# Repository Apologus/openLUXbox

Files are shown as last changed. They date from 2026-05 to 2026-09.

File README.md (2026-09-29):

# openLUXbox
## DIY-Open-Source-Coop-**Spielekonsole**
### Bauanleitung, 3D-Dateien, Dokumentation

*openLUXbox ist eine offene DIY-Spielekonsole für unter 40€ – gebaut zum Spielen, gedacht zum Weitermachen.*

Die openLUXbox wurde durch das *WLED Project* und das *Open LED Race Project* inspiriert. Die Grundidee besteht darin, eine einfache DIY-Hardware als Basis für **kooperative Spiele** zu nutzen. Die Steuerung erfolgt über vier integrierte Push-Buttons.

Die Hardware besteht aus einer LED-Matrix (WS2812b, 16x16 LEDs), einem ESP8266, 4 Buttons und wenigen Kleinteilen. Das Gehäuse ist 3D-gedruckt. Die Gesamtkosten bei ca. 30€.

Sämtliche Dokumente (Bauanleitung, Dokumentation, 3D-Druckdateien, Anleitung zum Programmieren) stehen frei zur Verfügung.

Die Zahl der Spiele wächst stetig. Diese können über einen Webflasher direkt aufgespielt werden. Das Besondere ist, dass diese Spiele per *Vibe Coding* entstanden sind. Das heißt, die Beschreibung der gewünschten Spielefunktion wurde durch KI in Arduino-Code umgesetzt. Dadurch sind nur rudimentäre Programmierkenntnisse notwendig, um **eigene Spiele** zu erstellen.

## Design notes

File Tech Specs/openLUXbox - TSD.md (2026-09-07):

### Technichal Specification Document

Dieses Dokument beschreibt die Funktionen und Spezifikationen einer Spielekonsole, die einen ESP8266  als Prozessor und eine 16x16 LED-Matrix als Ausgabe hat. 4 Buttons dienen der Bedienung und Steuerung.

## 1\. Hardware

### 1.1 Microcontroller:

D1 Mini NodeMcu mit ESP8266-12F
Treiber: "NodeMCU 1.0 (ESP-12E Module)" soll als Hinweis in jedem Code ganz oben stehen.

### 1.2 Display

RGB LED Panel WS2812B 16x16 256 LEDs

Helligkeit: 20%
Angesteuert über GPIO D4 mit FastLED.
Wlan/Watchdogs deaktiviert.
Framerate abhängig vom jeweiligen Spiel. Ziel: 30 FPS.

LED-Matrix Verkabelung:
- Typ: WS2812B, 16x16, 256 LEDs, Serpentinen-Layout
- Startpunkt: oben rechts
- Zeile 0 (oben): läuft von rechts nach links (Index 0 = oben rechts)
- Zeile 1: läuft von links nach rechts
- Gerade Zeilen (0, 2, 4, ...): rechts → links
- Ungerade Zeilen (1, 3, 5, ...): links → rechts

Koordinaten-Mapping (olb_xy):
  if (y % 2 == 0) → Index = y * 16 + (15 - x)   // rechts→links
  if (y % 2 == 1) → Index = y * 16 + x           // links→rechts

Bilddaten in den FRAME-Arrays sind logisch gespeichert:
  Index 0 = oben links, zeilenweise von links nach rechts.
  Die olb_xy()-Funktion übernimmt die Umsetzung auf die physikalische Verkabelung.

### 1.3 Buttons

4 Pushbuttons an GPIO

| | | | |
| --- | --- | --- | --- |
| D-PIN | GPIO | Richtung | Buttonfarbe |
| D5  | 14  | links | gelb |
| D2  | 4 | rechts | grün |
| D1  | 5 | unten | weiß |
| D6  | 12  | hoch | blau |

#### 1.3.1 Button Electrical Specification

Die Pushbuttons sind jeweils wie folgt verschaltet:

- Ein Kontakt des Buttons liegt am GPIO-Pin
- Der andere Kontakt liegt an GND
- Es sind keine externen Widerstände verbaut

###### 1.3.1.1 Elektrisches Verhalten

- Interne Pullup-Widerstände des ESP8266 werden verwendet
- Pin-Konfiguration im Code:
    - pinMode(PIN, INPUT_PULLUP)

##### 1.3.2 Logik

- Ruhestand (nicht gedrückt): HIGH
- Gedrückt: LOW
- Interpretation im Code:
    - digitalRead(pin) == LOW → Button gedrückt
    - digitalRead(pin) == HIGH → Button nicht gedrückt

##### 1.3.3 Taster-Auswertung

- Ein Tastendruck wird nur beim Flankenwechsel erkannt:
    - HIGH → LOW
- Gedrückt-Halten darf keine Mehrfachbewegung auslösen
- Entprellung per Software mit 30ms Sperrzeit nach Flankenwechsel

### 1.4 Weiteres

Tonausgabe ist nicht implementiert.
Eine Debug-Ausgabe erfolgt über den Seriellen Monitor.

## 2\. Coding Guidelines

- Der Code muss vollständig Arduino-IDE kompatibel sein
- Alle Funktionen müssen entweder:
    - vor ihrem ersten Aufruf definiert sein
    - oder per Prototyp deklariert werden
- Funktions-Prototypen müssen nach den Includes stehen
- Keine Abhängigkeit von automatischer Arduino-Prototypgenerierung
- Alle Spielparameter müssen als Konstanten im oberen Codebereich definiert sein
- Gameplay-Logik darf nicht blockierend sein (millis-basiert)
- Der Code muss strukturiert sein:
    - Includes
    - Defines
    - Structs
    - Prototypen
    - Globale Variablen
    - setup()
    - loop()
    - Funktionsimplementierungen
- Zufallsfunktionen sollen nicht bei jedem Spielstart die gleichen Werte liefern. Die Werte sollen wirklich zufällig sein: Seed wird aus `analogRead` eines unbeschalteten Pins ermittelt.
- Startbildschirm vor Start eines Spiels.
- Bei Game over ein entsprechender Bildschirm. Neustart nach Tastendruck.
- Weitere Design-Regeln werden im jeweiligen Game Specification Document erläutert.

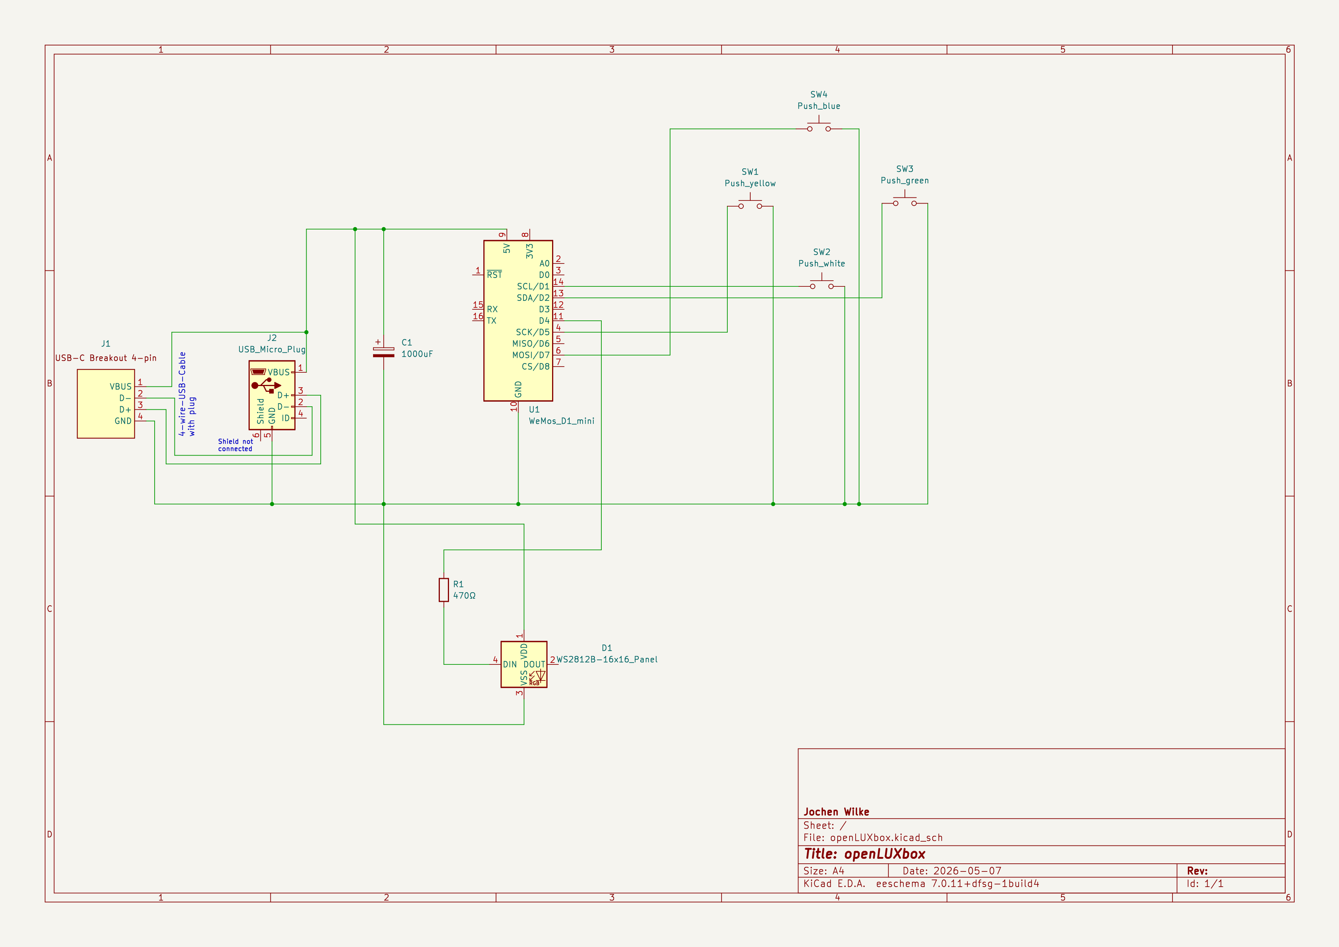
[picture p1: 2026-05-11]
Tech Specs/openLUXbox_kicad.png

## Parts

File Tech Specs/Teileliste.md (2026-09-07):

## Teileliste

Die Links sind *keine* affiliate links. Nachdem AZ-Delivery leider Konkurs angemeldet hat, stammen alle Links von Amazon.

- **ESP8266 Mini NodeMcu**: bei [Amazon](https://www.amazon.de//dp/B0C3LTYZDN).
- **LED Panel 16x16**: bei [Amazon](https://www.amazon.de/dp/B0DQSLL8P5).
- **USB-C-Buchsen** bei [Amazon](https://www.amazon.de/dp/B0CWNW6686).
- **USB-C-Anschlusskabel** bei  [Amazon](https://www.amazon.de/dp/B0CWNW6686).
- **Push Buttons**: bei [Amazon](https://www.amazon.de/dp/B0C5X3N5SR).
- **Widerstand 470 Ohm**: bei [Amazon](https://www.amazon.de/dp/B07BPK8V62).
- **Kondensatoren 1000uF**: bei [Amazon](https://www.amazon.de/dp/B0CMQBD1C3).

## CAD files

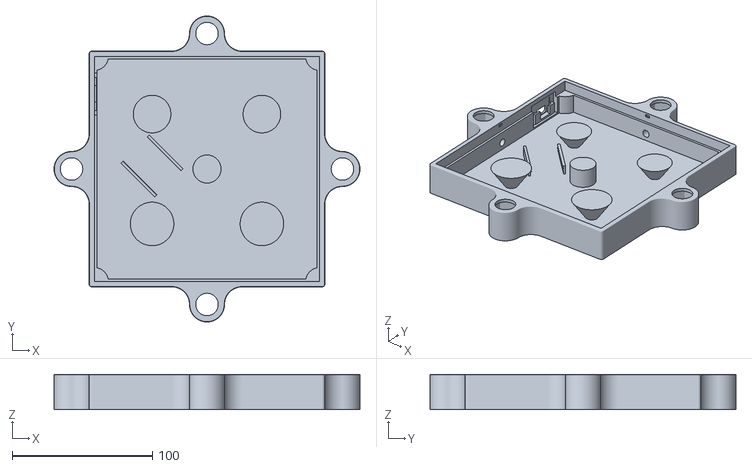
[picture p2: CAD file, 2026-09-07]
3d files/OpenLuxBox_Case_v2a.stl
218.0 x 218.0 x 25.0

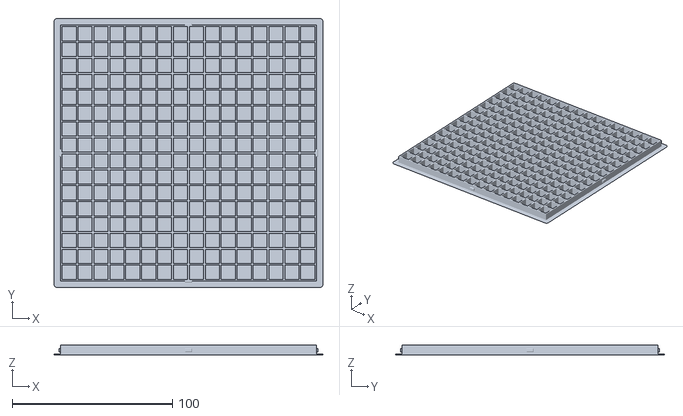
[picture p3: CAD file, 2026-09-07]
3d files/OpenLuxBox_Cover_v2a.stl
168.0 x 168.0 x 6.47

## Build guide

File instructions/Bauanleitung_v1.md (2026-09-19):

# openLUXbox
## Bauanleitung V1
Diese Anleitung beschreibt den Bau der openLUXbox v1. Alle benötigten Teile können selbst bestellt werden (siehe Teileliste). Case + Cover müssen 3d-gedruckt werden. Dieser vereinfache Aufbau ist inspiriert von 1ST1 aus dem [Homecon-Forum](https://forum.homecon.org/). 
### Case + Cover
Beide Teile sind mit PLA gedruckt. 
Das Case wird in einem Stück gedruckt. Dabei sind Stützen zu aktivieren. 
Das Cover besteht ebenfalls aus PLA. Die ersten Schichten sind einfach weißes PLA, das trennende Raster schwarzes PLA. Ohne Multifarbdrucker ist beim Slicen mit dem Beginn des Rasters ein Farbwechsel einzustellen.

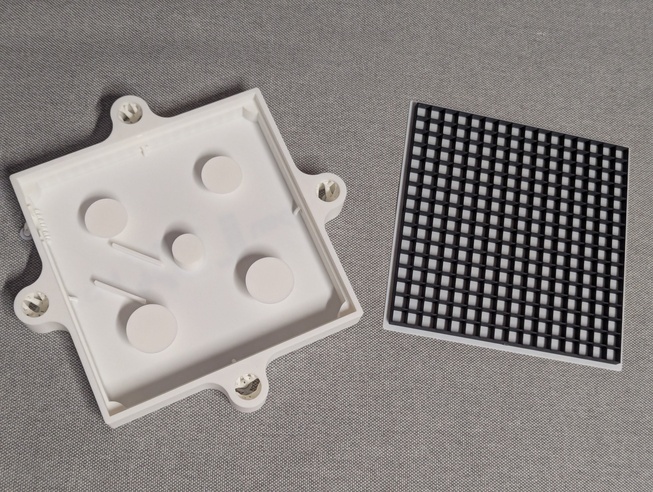
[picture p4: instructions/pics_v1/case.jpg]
Gehäuse


### Verkabelung
Der ESP8266 wird später in diese Halterung geschoben.

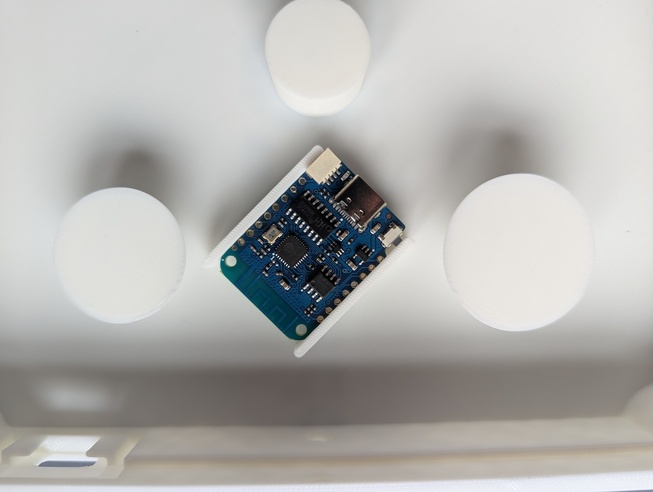
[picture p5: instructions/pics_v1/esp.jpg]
ESP


Die Stromversorgung erfolgt über eine USB-C-Buchse, an die ein Stecker angelötet wird. Dieser versorgt den ESP mit +5V/GND und zwei Datenleitungen, um Spiele zu flashen.

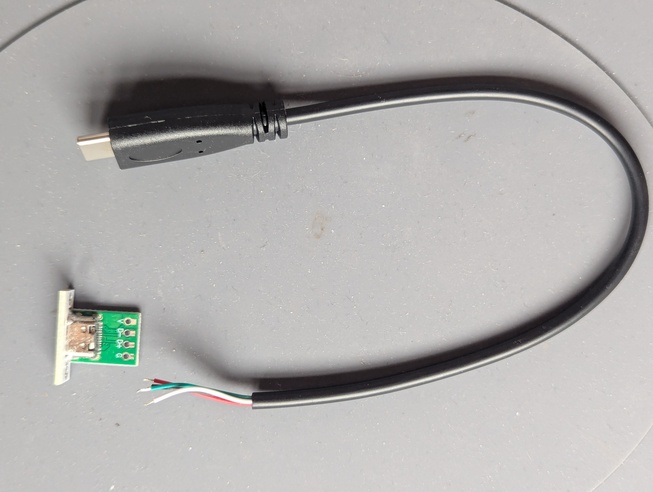
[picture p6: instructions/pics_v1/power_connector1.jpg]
Power Connector

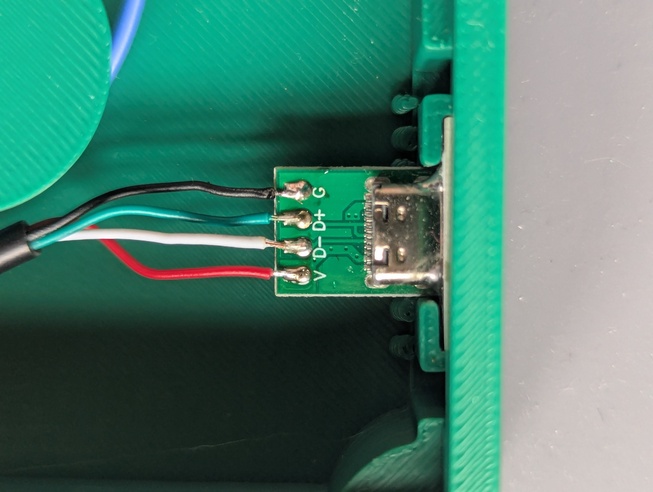
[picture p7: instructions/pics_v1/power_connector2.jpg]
Power Connector


Die Buttons haben einen Distanzring und eine Gewindemutter. Zwei Kabel (ca. 20cm) werden angelötet (oder sind es bereits).

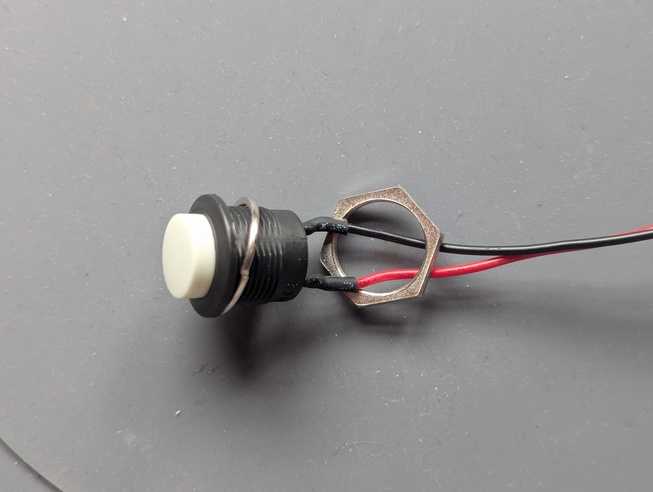
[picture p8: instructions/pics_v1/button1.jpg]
Button


Die Mutter wird von unten in den Halterungen der Buttons gesetzt.

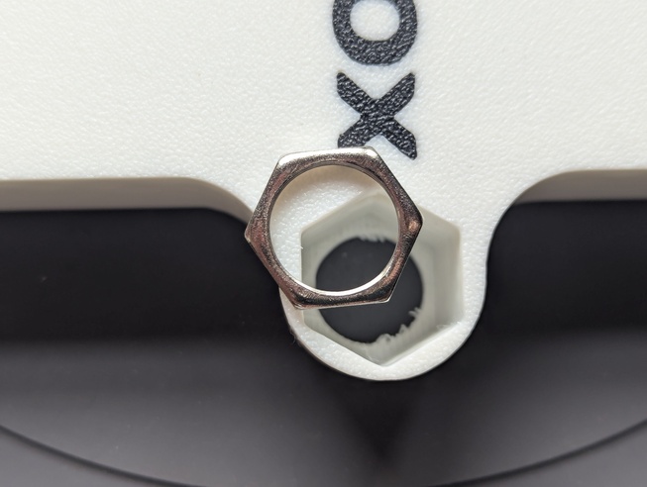
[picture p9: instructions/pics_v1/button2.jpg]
Button


Der Buttton wird dann von oben mit Distanzring und Kabeln eingeführt und in die Mutter eingedreht. Sitzt der Button fest, werden die beiden Kabel durch die Öffnung nach innen geführt.

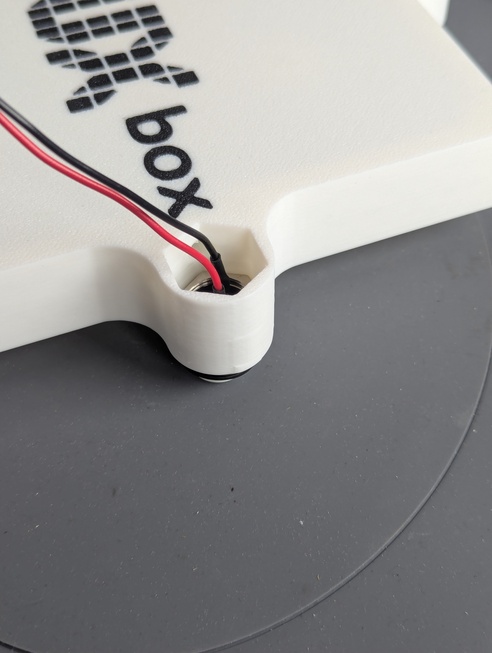
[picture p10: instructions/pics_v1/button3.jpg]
Button

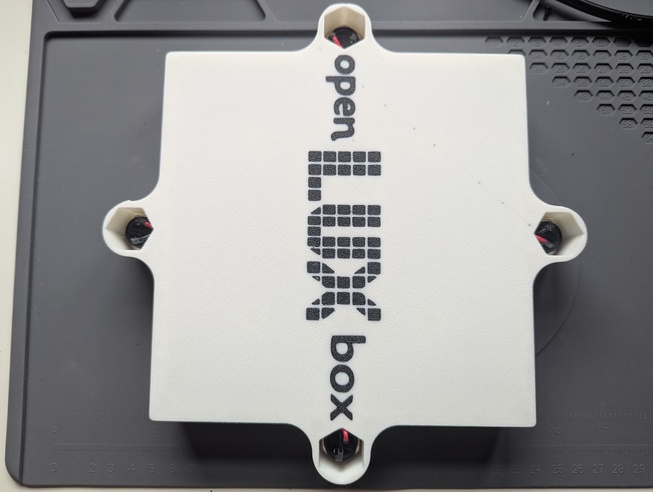
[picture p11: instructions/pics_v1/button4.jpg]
Button

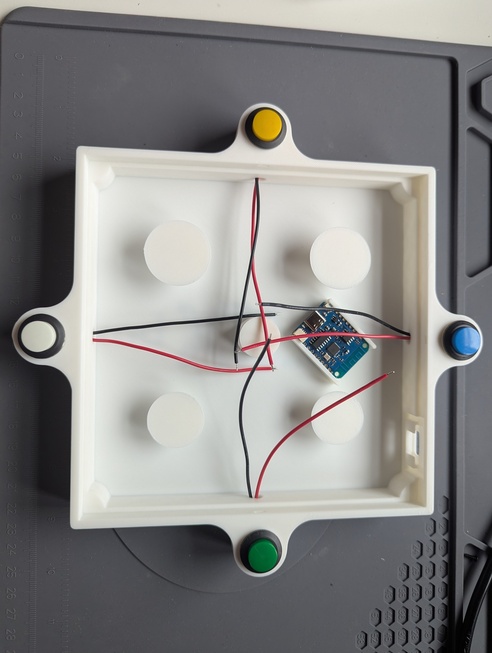
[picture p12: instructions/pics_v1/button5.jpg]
Button


Die roten Kabel der Buttons entweder direkt an den ESP gelötet werden. Alternativ (wie im Bild) lötet man kurze Verbindungskabel in der jeweiligen Buttonfarbe an den ESP. Diese werden dann mit den roten Kabeln des jeweiligen Buttons verbunden.

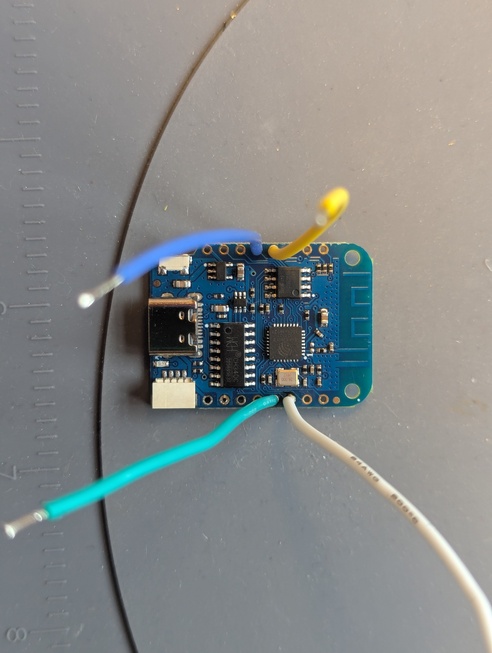
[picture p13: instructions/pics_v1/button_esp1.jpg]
Button_esp

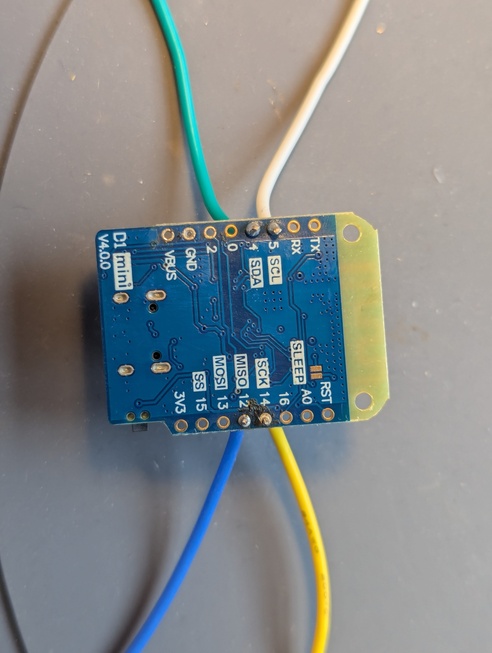
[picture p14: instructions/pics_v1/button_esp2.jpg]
Button_esp


Zwischen ESP und die Datenverbindung des LED (grünes Kabel) wird der Widerstand gelötet.

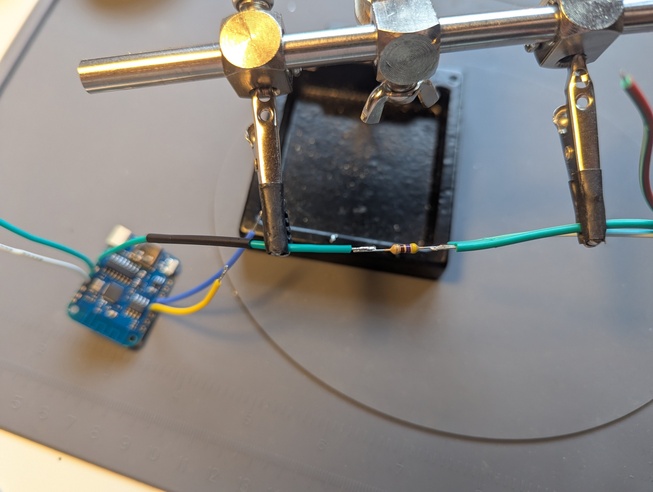
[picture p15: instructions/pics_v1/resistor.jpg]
resistor


Hier die vollständige Beschaltung des ESP.

PIN 4 ist dabei der grüne Button. PIN 2 die Datenverbindung zum LED.

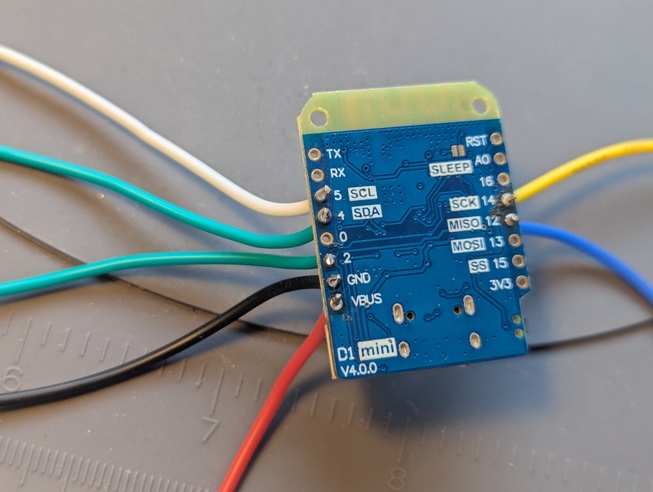
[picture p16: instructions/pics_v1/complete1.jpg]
complete1

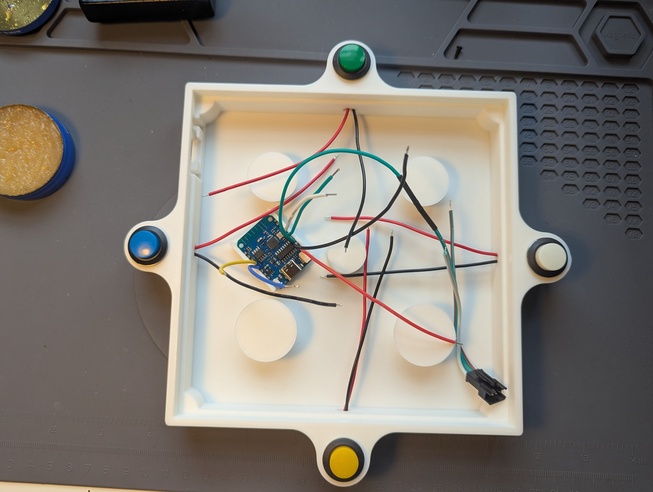
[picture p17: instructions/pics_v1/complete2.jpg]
complete2


Der Kondensator und die Spannungsversorgung des LED-Panels werden direkt an die USB-C-Buchse (von unten) gelötet.

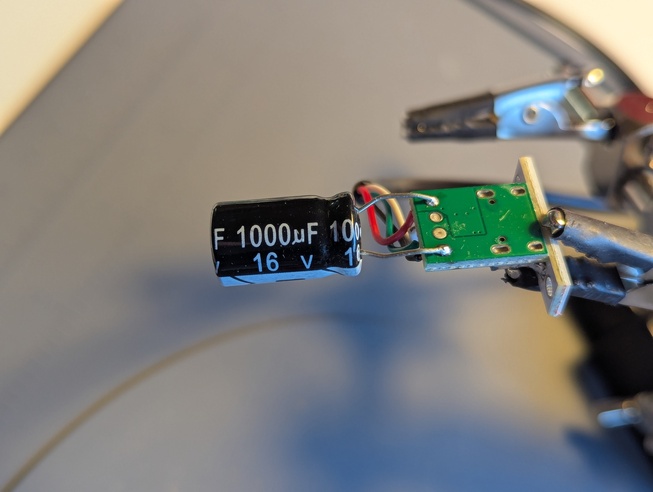
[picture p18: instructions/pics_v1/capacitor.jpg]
capacitor

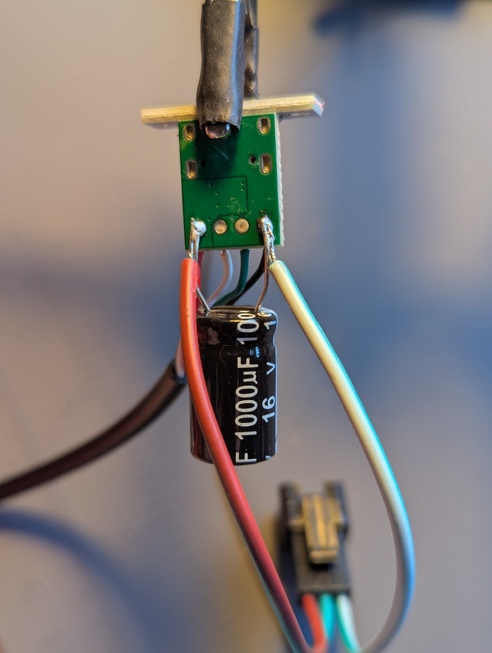
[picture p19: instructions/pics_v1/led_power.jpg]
led_power


Die vier schwarzen Kabel der Buttons (GRD) werden miteinander und einem weiteren Kabel verlötet. Das weitere Kabel kommt ebenfalls an GRD der USB-C-Buchse. Alle fünf Kabel am besten mit Schrumpfschlauch schützen.

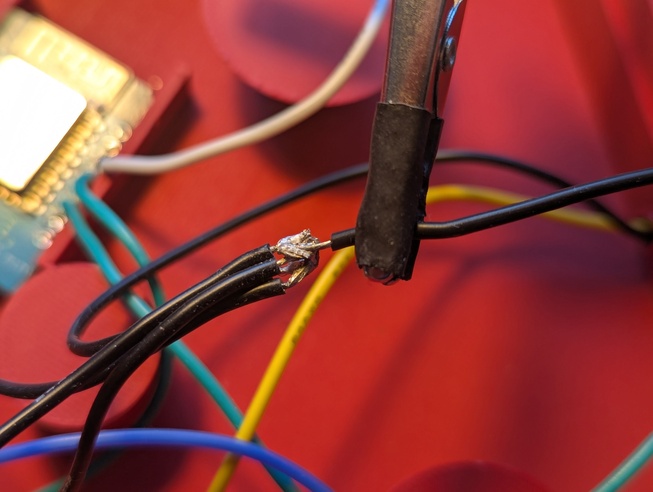
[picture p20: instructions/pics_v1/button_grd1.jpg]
button_grd1

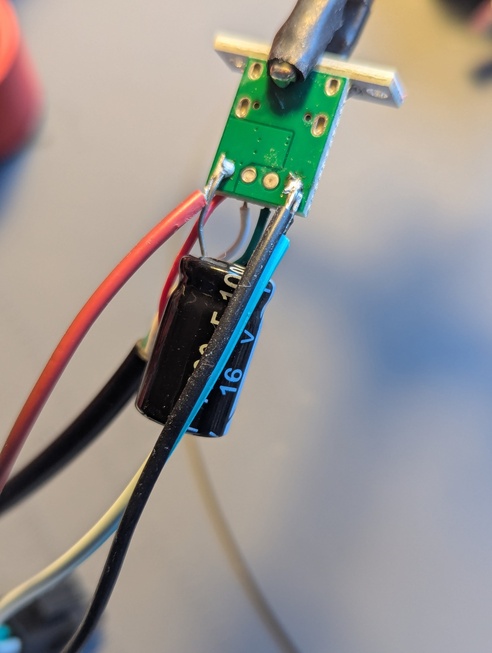
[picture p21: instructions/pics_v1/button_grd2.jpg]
button_grd2


Der komplette Aufbau sieht dann so aus.

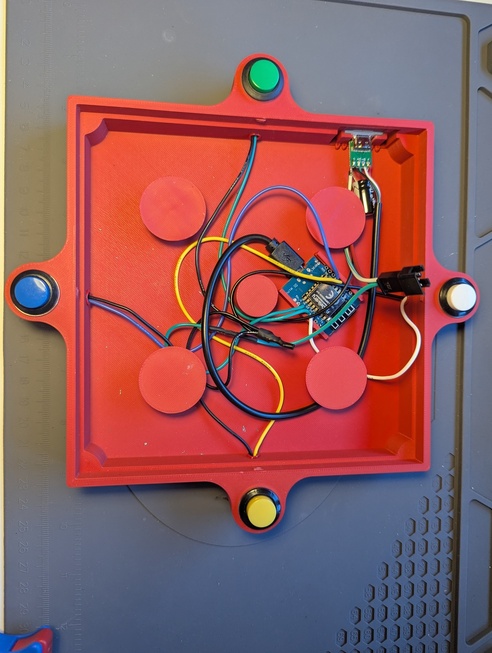
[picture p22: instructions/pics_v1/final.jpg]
final


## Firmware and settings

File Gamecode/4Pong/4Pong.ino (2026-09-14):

// NodeMCU 1.0 (ESP-12E Module)
// 4Pong - openLUXbox

#include <FastLED.h>
#include <ESP8266WiFi.h>
#include "olb_init_v1.h"

// ============================================================
// DEFINES / PARAMETER
// ============================================================
#define LED_PIN        D4
#define NUM_LEDS       256
#define MATRIX_W       16
#define MATRIX_H       16
#define BRIGHTNESS     51   // 20% von 255

#define BTN_LEFT       4    // D2 grün
#define BTN_RIGHT      14   // D5 gelb
#define BTN_DOWN       5    // D1 weiß
#define BTN_UP         12   // D6 blau

#define FPS            30
#define FRAME_MS       (1000 / FPS)

#define BALL_START_SPEED     4.0f
#define BALL_SPEED_INC       1.0f
#define BALL_SPEED_INTERVAL  10000

#define PADDLE_SIZE           4
#define PADDLE_DEFLECT_ANGLE  10.0f

#define GAMEOVER_SPEED 12.0f

#define DEBOUNCE_MS    30

// Farben
#define COL_BLACK      CRGB(0,0,0)
#define COL_BALL       CRGB(180,0,255)
#define COL_YELLOW     CRGB(255,255,80)
#define COL_GREEN      CRGB(80,255,80)
#define COL_BLUE       CRGB(80,160,255)
#define COL_WHITE      CRGB(255,255,255)
#define COL_CYAN       CRGB(80,255,255)
#define COL_MAGENTA    CRGB(255,80,255)

// ============================================================
// STARTBILDSCHIRM - FEST INTEGRIERTER HEXCODE
// ============================================================
const uint32_t PROGMEM SCREEN_START[16][16] = {
    {0x4F2189, 0x4E2189, 0x4F2189, 0x4F2089, 0x4F2189, 0x4F2089, 0x4F218A, 0x4F218A, 0x4F218A, 0x4F218A, 0x4F218A, 0x50218B, 0x50218B, 0xF4F13A, 0x532390, 0x5D26A2},
    {0x50218B, 0x50218B, 0x50218B, 0x50218B, 0x50218B, 0x51218C, 0x50228D, 0x51228E, 0x51228E, 0x52228E, 0x532290, 0x542291, 0xF4F13A, 0xF4F13A, 0x5C26A0, 0x652AB0},
    {0x50218B, 0x000000, 0x000000, 0x000000, 0x000000, 0x000000, 0x522290, 0x532391, 0x532291, 0x542392, 0x552394, 0xF4F13A, 0x58259A, 0xF4F13A, 0x6028A7, 0x672BB2},
    {0x50218B, 0x000000, 0x52228F, 0x522291, 0x532391, 0x000000, 0x000000, 0x552493, 0x552495, 0x572496, 0xF4F13A, 0x5A259B, 0x5C26A0, 0xF4F13A, 0x6229AB, 0x672AB3},
    {0x50218B, 0x000000, 0x532392, 0x542392, 0x542393, 0x552394, 0x000000, 0x562497, 0x572498, 0xF4F13A, 0x5A259C, 0x5C26A0, 0x5D27A3, 0xF4F13A, 0x6329AD, 0x672BB4},
    {0x50218B, 0x000000, 0x542393, 0x552394, 0x562396, 0x572396, 0x000000, 0x582499, 0x59259B, 0xF4F13A, 0xF4F13A, 0xF4F13A, 0xF4F13A, 0xF4F13A, 0xF4F13A, 0x672BB4},
    {0x50218B, 0x000000, 0x562396, 0x562496, 0x572497, 0x000000, 0x000000, 0x5A259C, 0x5A259D, 0x5B269F, 0x5C26A2, 0x5E27A5, 0x6027A8, 0xF4F13A, 0x652AB1, 0x682BB5},
    {0x50218B, 0x000000, 0x000000, 0x000000, 0x000000, 0x000000, 0x59259B, 0x5A269E, 0x5B26A0, 0x5C26A1, 0x5E27A4, 0x6028A6, 0x6129AA, 0xF4F13A, 0x662AB1, 0x672BB5},
    {0x50218B, 0x000000, 0x572499, 0x58259A, 0x59259A, 0x5A259C, 0x5A259D, 0x5C269F, 0x5C26A2, 0x5D26A4, 0x5F27A6, 0x6028A8, 0x6229AB, 0x642AAE, 0x662AB1, 0x682BB5},
    {0x50218B, 0x000000, 0x58259A, 0x59259C, 0x000000, 0x000000, 0x5C269F, 0x5D26A1, 0x000000, 0x000000, 0x000000, 0x6228AA, 0x6229AD, 0x000000, 0x000000, 0x000000},
    {0x50218B, 0x000000, 0x5A259C, 0x000000, 0x5B259E, 0x5C269F, 0x000000, 0x5E26A2, 0x000000, 0x5F28A6, 0x000000, 0x6228AB, 0x000000, 0x6529B0, 0x662AB2, 0x000000},
    {0x50218B, 0x000000, 0x5A269D, 0x000000, 0x5C26A0, 0x5C26A1, 0x000000, 0x5E27A4, 0x000000, 0x6027A8, 0x000000, 0x6329AC, 0x000000, 0x652AB1, 0x672BB3, 0x000000},
    {0x5A259C, 0x5A269E, 0x5B269E, 0x5B269F, 0x000000, 0x000000, 0x5E27A3, 0x5F27A5, 0x000000, 0x6028A9, 0x000000, 0x6329AC, 0x642AAE, 0x000000, 0x000000, 0x000000},
    {0x5B259E, 0x5B259E, 0x5B259F, 0x5C27A0, 0x5D26A2, 0x5E26A3, 0x5E27A4, 0x5F28A6, 0x6028A7, 0x6128A9, 0x6229AB, 0x6329AD, 0x6429AF, 0x652AB2, 0x662AB3, 0x000000},
    {0x5B269E, 0x5B269F, 0x5C26A0, 0x5D27A2, 0x5D27A3, 0x5E27A4, 0x5F28A5, 0x5F28A7, 0x6128A8, 0x6229AA, 0x6329AB, 0x642AAE, 0x642AAF, 0x000000, 0x000000, 0x682BB5},
    {0x5C269F, 0x5C26A0, 0x5C26A1, 0x5D27A3, 0x5E27A3, 0x5F27A5, 0x5F27A6, 0x6028A7, 0x6128A9, 0x6228AA, 0x6329AC, 0x642AAE, 0x652AB0, 0x662AB2, 0x672BB4, 0x682BB5}
};

// ============================================================
// STRUCTS
// ============================================================
struct Button {
  uint8_t pin;
  bool lastState;
  bool pressed;
  unsigned long lastDebounce;
};
struct Paddle {
  int pos;
  int minPos;
  int maxPos;
};

// ============================================================
// PROTOTYPEN
// ============================================================
void clearMatrix();
void showStartScreen();
void startGame();
void updateButtons();
bool anyButtonPressed();
void handleInput();
void updateBall(unsigned long delta_ms);
void drawPaddles();
void drawBall();
int  xyToIndex(int x, int y);
bool isOnPaddle(int x, int y, int &paddleId, int &half);
void reflectBall(int paddleId, int half);
void fillGameOverPixels();
CRGB randomColor();

// ============================================================
// GLOBALE VARIABLEN
// ============================================================
CRGB leds[NUM_LEDS];

Button btnLeft  = {BTN_LEFT,  HIGH, false, 0};
Button btnRight = {BTN_RIGHT, HIGH, false, 0};
Button btnDown  = {BTN_DOWN,  HIGH, false, 0};
Button btnUp    = {BTN_UP,    HIGH, false, 0};
Button* buttons[4] = {&btnLeft, &btnRight, &btnDown, &btnUp};

Paddle paddles[4];

float ballX, ballY;
float ballAngle;
float ballSpeed;

unsigned long lastSpeedUp;
int score;

enum GameState { STATE_START, STATE_PLAY, STATE_GAMEOVER };
GameState gameState;

int   gameOverPixels;
float gameOverAccum;
CRGB  gameOverColor;
int   gameOverRound;
bool  gameOverScreenCleared;

unsigned long lastFrameTime;

// Verhindert sofortigen Start nach Boot
bool startScreenJustShown = false;

// ============================================================
// SETUP
// ============================================================
void setup() {
  Serial.begin(115200);
  delay(1500); // ESP boot stabilisieren
  Serial.println("[4Pong] Setup gestartet");

  WiFi.mode(WIFI_OFF);
  WiFi.forceSleepBegin();
  delay(100);
  // KEIN wdtDisable() – kann Boot blockieren

  pinMode(BTN_LEFT,  INPUT_PULLUP);
  pinMode(BTN_RIGHT, INPUT_PULLUP);
  pinMode(BTN_DOWN,  INPUT_PULLUP);
  pinMode(BTN_UP,    INPUT_PULLUP);
  pinMode(D3, INPUT);

  FastLED.addLeds<WS2812B, LED_PIN, GRB>(leds, NUM_LEDS);

  //Startanimation
  olb_v1_playIntro(leds);

  FastLED.setBrightness(BRIGHTNESS);

  // Verbesserter Random Seed
  uint32_t seed = 0;
  for (int i = 0; i < 32; i++) {
    seed ^= (uint32_t)analogRead(A0) << (i % 16);
    delay(1);
  }
  for (int i = 0; i < 16; i++) {
    seed ^= (uint32_t)digitalRead(D3) << i;
  }
  randomSeed(seed);
  Serial.print("[4Pong] Random Seed: ");
  Serial.println(seed);

  // Startscreen zeichnen
  clearMatrix();
  FastLED.show();
  delay(100);
  showStartScreen();
  gameState = STATE_START;

  // Buttons NACH Startscreen initialisieren – Bounce vermeiden
  delay(300);
  for (int i = 0; i < 4; i++) {
    buttons[i]->lastState = digitalRead(buttons[i]->pin);
    buttons[i]->pressed   = false;
  }

  // Flag: ersten Loop-Durchlauf ignorieren
  startScreenJustShown = true;

  lastFrameTime = millis();
  Serial.println("[4Pong] Warte auf Tastendruck...");
}

// ============================================================
// LOOP
// ============================================================
void loop() {
  yield(); // WDT-freundlich, kein wdtFeed nötig

  unsigned long now = millis();
  unsigned long delta = now - lastFrameTime;
  if (delta < FRAME_MS) return;
  lastFrameTime = now;

  updateButtons();

  switch (gameState) {

    case STATE_START:
      // Ersten Frame nach Boot überspringen
      if (startScreenJustShown) {
        startScreenJustShown = false;
        return;
      }
      if (anyButtonPressed()) {
        Serial.println("[4Pong] Startbildschirm: Taste gedrückt -> Spiel startet");
        startGame();
      }
      break;

    case STATE_PLAY:
      handleInput();
      updateBall(delta);
      if (gameState == STATE_PLAY) {
        clearMatrix();
        drawPaddles();
        drawBall();
        FastLED.show();
      }
      break;

    case STATE_GAMEOVER:
      if (!gameOverScreenCleared) {
        clearMatrix();
        FastLED.show();
        gameOverScreenCleared = true;
        Serial.println("[GAMEOVER] Screen geleert, starte Score-Animation");
      } else if (anyButtonPressed()) {
        Serial.println("[GAMEOVER] Taste gedrückt -> Startbildschirm");
        delay(2000);
        showStartScreen();
        gameState = STATE_START;
        // Auch hier: Flag setzen damit kein Doppel-Trigger
        startScreenJustShown = true;
      } else {
        fillGameOverPixels();
        FastLED.show();
      }
      break;
  }
}

// ============================================================
// HILFSFUNKTIONEN
// ============================================================
int xyToIndex(int x, int y) {
  if (x < 0 || x >= MATRIX_W || y < 0 || y >= MATRIX_H) return -1;
  if (y % 2 == 0) {
    return y * MATRIX_W + x;
  } else {
    return y * MATRIX_W + (MATRIX_W - 1 - x);
  }
}

void clearMatrix() {
  fill_solid(leds, NUM_LEDS, COL_BLACK);
}

void showStartScreen() {
  Serial.println("[4Pong] Zeige integrierten Startbildschirm...");
  for (int y = 0; y < MATRIX_H; y++) {
    for (int x = 0; x < MATRIX_W; x++) {
      uint32_t color = pgm_read_dword(&SCREEN_START[y][MATRIX_W - 1 - x]);
      uint8_t r = (color >> 16) & 0xFF;
      uint8_t g = (color >> 8)  & 0xFF;
      uint8_t b =  color        & 0xFF;
      int idx = xyToIndex(x, y);
      if (idx >= 0) leds[idx] = CRGB(r, g, b);
    }
  }
  FastLED.show();
  Serial.println("[4Pong] Startbildschirm angezeigt");
}

// ============================================================
// SPIEL INITIALISIEREN
// ============================================================
void startGame() {
  paddles[0].pos    = (MATRIX_W - PADDLE_SIZE) / 2;
  paddles[0].minPos = 0;
  paddles[0].maxPos = MATRIX_W - PADDLE_SIZE;

  paddles[1].pos    = (MATRIX_W - PADDLE_SIZE) / 2;
  paddles[1].minPos = 0;
  paddles[1].maxPos = MATRIX_W - PADDLE_SIZE;

  paddles[2].pos    = (MATRIX_H - PADDLE_SIZE) / 2;
  paddles[2].minPos = 0;
  paddles[2].maxPos = MATRIX_H - PADDLE_SIZE;

  paddles[3].pos    = (MATRIX_H - PADDLE_SIZE) / 2;
  paddles[3].minPos = 0;
  paddles[3].maxPos = MATRIX_H - PADDLE_SIZE;

  Serial.println("[4Pong] Schläger initialisiert (alle mittig)");

  ballX     = 7.5f;
  ballY     = 7.5f;
  ballSpeed = BALL_START_SPEED;
  lastSpeedUp = millis();
  score = 0;
  // Diagonaler Startwinkel, nie achsenparallel
  int baseAngles[] = {30, 60, 120, 150, 210, 240, 300, 330};
  ballAngle = baseAngles[random(0, 8)] + random(-10, 10);

  Serial.print("[4Pong] Ball startet: Winkel=");
  Serial.print(ballAngle);
  Serial.println(" Grad");

  gameOverPixels        = 0;
  gameOverAccum         = 0;
  gameOverColor         = COL_BALL;
  gameOverRound         = 0;
  gameOverScreenCleared = false;

  gameState = STATE_PLAY;
}

// ============================================================
// BUTTONS
// ============================================================
void updateButtons() {
  unsigned long now = millis();
  for (int i = 0; i < 4; i++) {
    Button* b = buttons[i];
    b->pressed = false;
    bool current = digitalRead(b->pin);
    if (current == LOW && b->lastState == HIGH) {
      if (now - b->lastDebounce > DEBOUNCE_MS) {
        b->pressed = true;
        b->lastDebounce = now;
        Serial.print("[BTN] Taste gedrückt: Index=");
        Serial.println(i);
      }
    }
    b->lastState = current;
  }
}

bool anyButtonPressed() {
  for (int i = 0; i < 4; i++) {
    if (buttons[i]->pressed) return true;
  }
  return false;
}

// ============================================================
// INPUT -> SCHLÄGER BEWEGEN
// ============================================================
void handleInput() {
  if (btnLeft.pressed) {
    if (paddles[0].pos > paddles[0].minPos) { paddles[0].pos--; Serial.println("[INPUT] Oben nach links"); }
    else Serial.println("[INPUT] Oben bereits am linken Rand");
    if (paddles[1].pos > paddles[1].minPos) { paddles[1].pos--; Serial.println("[INPUT] Unten nach links"); }
    else Serial.println("[INPUT] Unten bereits am linken Rand");
  }
  if (btnRight.pressed) {
    if (paddles[0].pos < paddles[0].maxPos) { paddles[0].pos++; Serial.println("[INPUT] Oben nach rechts"); }
    else Serial.println("[INPUT] Oben bereits am rechten Rand");
    if (paddles[1].pos < paddles[1].maxPos) { paddles[1].pos++; Serial.println("[INPUT] Unten nach rechts"); }
    else Serial.println("[INPUT] Unten bereits am rechten Rand");
  }
  if (btnUp.pressed) {
    if (paddles[2].pos > paddles[2].minPos) { paddles[2].pos--; Serial.println("[INPUT] Links nach oben"); }
    else Serial.println("[INPUT] Links bereits am oberen Rand");
    if (paddles[3].pos > paddles[3].minPos) { paddles[3].pos--; Serial.println("[INPUT] Rechts nach oben"); }
    else Serial.println("[INPUT] Rechts bereits am oberen Rand");
  }
  if (btnDown.pressed) {
    if (paddles[2].pos < paddles[2].maxPos) { paddles[2].pos++; Serial.println("[INPUT] Links nach unten"); }
    else Serial.println("[INPUT] Links bereits am unteren Rand");
    if (paddles[3].pos < paddles[3].maxPos) { paddles[3].pos++; Serial.println("[INPUT] Rechts nach unten"); }
    else Serial.println("[INPUT] Rechts bereits am unteren Rand");
  }
}

// ============================================================
// BALL UPDATE
// ============================================================
void updateBall(unsigned long delta_ms) {
  unsigned long now = millis();
  if (now - lastSpeedUp >= BALL_SPEED_INTERVAL) {
    ballSpeed += BALL_SPEED_INC;
    lastSpeedUp = now;
    Serial.print("[BALL] Geschwindigkeit erhöht auf ");
    Serial.println(ballSpeed);
  }

  float rad = ballAngle * PI / 180.0f;
  float dx = cos(rad) * ballSpeed * delta_ms / 1000.0f;
  float dy = sin(rad) * ballSpeed * delta_ms / 1000.0f;

  float newX = ballX + dx;
  float newY = ballY + dy;

  int nx = (int)round(newX);
  int ny = (int)round(newY);

  if (nx < 0 || nx >= MATRIX_W || ny < 0 || ny >= MATRIX_H) {
    Serial.print("[BALL] Rand erreicht bei (");
    Serial.print(nx); Serial.print("/"); Serial.print(ny);
    Serial.print(") -> Game Over | Score: ");
    Serial.println(score);
    gameState             = STATE_GAMEOVER;
    gameOverPixels        = 0;
    gameOverAccum         = 0;
    gameOverColor         = COL_BALL;
    gameOverRound         = 0;
    gameOverScreenCleared = false;
    return;
  }

  int paddleId, half;
  if (isOnPaddle(nx, ny, paddleId, half)) {
    reflectBall(paddleId, half);
    score++;
    float rad2 = ballAngle * PI / 180.0f;
    ballX = nx + cos(rad2);
    ballY = ny + sin(rad2);
    Serial.print("[BALL] Schläger getroffen! Score=");
    Serial.println(score);
  } else {
    ballX = newX;
    ballY = newY;
  }
}

bool isOnPaddle(int x, int y, int &paddleId, int &half) {
  if (y == 0) {
    int p = paddles[0].pos;
    if (x >= p && x < p + PADDLE_SIZE) {
      paddleId = 0;
      half = (x < p + PADDLE_SIZE / 2) ? 0 : 1;
      return true;
    }
  }
  if (y == MATRIX_H - 1) {
    int p = paddles[1].pos;
    if (x >= p && x < p + PADDLE_SIZE) {
      paddleId = 1;
      half = (x < p + PADDLE_SIZE / 2) ? 0 : 1;
      return true;
    }
  }
  if (x == 0) {
    int p = paddles[2].pos;
    if (y >= p && y < p + PADDLE_SIZE) {
      paddleId = 2;
      half = (y < p + PADDLE_SIZE / 2) ? 0 : 1;
      return true;
    }
  }
  if (x == MATRIX_W - 1) {
    int p = paddles[3].pos;
    if (y >= p && y < p + PADDLE_SIZE) {
      paddleId = 3;
      half = (y < p + PADDLE_SIZE / 2) ? 0 : 1;
      return true;
    }
  }
  return false;
}

void reflectBall(int paddleId, int half) {
  float a = ballAngle;

  if (paddleId == 0 || paddleId == 1) {
    a = fmod(360.0f - a, 360.0f);
  } else {
    a = fmod(180.0f - a + 360.0f, 360.0f);
  }

  float deflect = 0;
  if (paddleId == 0 || paddleId == 1) {
    bool flyingLeft = (ballAngle > 90.0f && ballAngle < 270.0f);
    bool hitLeft    = (half == 0);
    deflect = (flyingLeft == hitLeft) ? PADDLE_DEFLECT_ANGLE : -PADDLE_DEFLECT_ANGLE;
  } else {
    bool flyingUp = (ballAngle > 180.0f && ballAngle < 360.0f);
    bool hitTop   = (half == 0);
    deflect = (flyingUp == hitTop) ? PADDLE_DEFLECT_ANGLE : -PADDLE_DEFLECT_ANGLE;
  }
  a = fmod(a + deflect + 360.0f, 360.0f);
  ballAngle = a;
}

// ============================================================
// ZEICHNEN
// ============================================================
void drawPaddles() {
  for (int i = 0; i < PADDLE_SIZE; i++) {
    int x = paddles[0].pos + i;
    CRGB col = (i < PADDLE_SIZE / 2) ? COL_GREEN : COL_YELLOW;
    int idx = xyToIndex(x, 0);
    if (idx >= 0) leds[idx] = col;
  }
  for (int i = 0; i < PADDLE_SIZE; i++) {
    int x = paddles[1].pos + i;
    CRGB col = (i < PADDLE_SIZE / 2) ? COL_GREEN : COL_YELLOW;
    int idx = xyToIndex(x, MATRIX_H - 1);
    if (idx >= 0) leds[idx] = col;
  }
  for (int i = 0; i < PADDLE_SIZE; i++) {
    int y = paddles[2].pos + i;
    CRGB col = (i < PADDLE_SIZE / 2) ? COL_BLUE : COL_WHITE;
    int idx = xyToIndex(0, y);
    if (idx >= 0) leds[idx] = col;
  }
  for (int i = 0; i < PADDLE_SIZE; i++) {
    int y = paddles[3].pos + i;
    CRGB col = (i < PADDLE_SIZE / 2) ? COL_BLUE : COL_WHITE;
    int idx = xyToIndex(MATRIX_W - 1, y);
    if (idx >= 0) leds[idx] = col;
  }

  // Ecken
  if (paddles[0].pos == 0 && paddles[2].pos == 0) {
    int idx = xyToIndex(0, 0);
    if (idx >= 0) leds[idx] = COL_MAGENTA;
  }
  if ((paddles[0].pos + PADDLE_SIZE - 1 >= MATRIX_W - 1) && paddles[3].pos == 0) {
    int idx = xyToIndex(MATRIX_W - 1, 0);
    if (idx >= 0) leds[idx] = COL_CYAN;
  }
  if (paddles[1].pos == 0 && (paddles[2].pos + PADDLE_SIZE - 1 >= MATRIX_H - 1)) {
    int idx = xyToIndex(0, MATRIX_H - 1);
    if (idx >= 0) leds[idx] = CRGB(255, 255, 128);
  }
  if ((paddles[1].pos + PADDLE_SIZE - 1 >= MATRIX_W - 1) && (paddles[3].pos + PADDLE_SIZE - 1 >= MATRIX_H - 1)) {
    int idx = xyToIndex(MATRIX_W - 1, MATRIX_H - 1);
    if (idx >= 0) leds[idx] = CRGB(128, 255, 128);
  }
}

void drawBall() {
  int bx = (int)round(ballX);
  int by = (int)round(ballY);
  int idx = xyToIndex(bx, by);
  if (idx >= 0) leds[idx] = COL_BALL;
}

// ============================================================
// GAME OVER ANIMATION
// ============================================================
CRGB randomColor() {
  return CRGB(random(100, 255), random(100, 255), random(100, 255));
}

void fillGameOverPixels() {
  gameOverAccum += GAMEOVER_SPEED / FPS;
  int toFill = (int)gameOverAccum;
  gameOverAccum -= toFill;

  for (int i = 0; i < toFill; i++) {
    if (gameOverRound == 0 && gameOverPixels >= score) {
      Serial.print("[GAMEOVER] Animation abgeschlossen, Score=");
      Serial.println(score);
      return;
    }

    int pixelInRound = gameOverPixels % NUM_LEDS;

    if (pixelInRound == 0 && gameOverPixels > 0) {
      gameOverRound++;
      gameOverColor = randomColor();
      Serial.print("[GAMEOVER] Neue Füllung, Runde=");
      Serial.println(gameOverRound);
    }

    int x = pixelInRound % MATRIX_W;
    int y = pixelInRound / MATRIX_W;
    int idx = xyToIndex(x, y);
    if (idx >= 0) leds[idx] = gameOverColor;

    gameOverPixels++;
  }
  delay(50);
}

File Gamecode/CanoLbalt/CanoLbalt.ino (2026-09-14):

// NodeMCU 1.0 (ESP-12E Module) - Board: "NodeMCU 1.0 (ESP-12E Module)"
// CanoLbalt - Co-op Runner gemäß GSD 

#include <user_interface.h>
#include <FastLED.h>
#include "olb_init_v1.h"

// ============================================================================
// 1. HARDWARE- UND PIN-DEFINITIONEN
// ============================================================================
#define PIN_LED           D4
#define NUM_LEDS          256
#define MATRIX_WIDTH      16
#define MATRIX_HEIGHT     16
#define COLOR_ORDER       GRB
#define CHIPSET           WS2812B
#define GLOBAL_BRIGHTNESS 80 // ~20% Helligkeit gemäß GSD

#define PIN_BTN_GELB      14 // GPIO 14 (D5) - Spieler 0 (GELB - LINKS)
#define PIN_BTN_GRUEN     4  // GPIO 4  (D2) - Spieler 1 (GRÜN - RECHTS)
#define PIN_BTN_WEISS     5  // GPIO 5  (D1) - Spieler 2 (WEISS - UNTEN)
#define PIN_BTN_BLAU      12 // GPIO 12 (D6) - Spieler 3 (BLAU - HOCH/OBEN)

#define NUM_PLAYERS       4

// ============================================================================
// 2. SPIELFLUSS & CONFIGURATION (ALLE FEATURE-SWITCHES AN EINEM ORT)
// ============================================================================
// --- DEV MODE SCHALTER ---
const bool DEV_MODE                   = false; // true = 4-Tasten-Cheat/Testmodus erlaubt, false = Exakt die 2 Duo-Tasten nötig

// --- BASE SPEED & PROGRESSION ---
float    SCROLL_SPEED_INIT_PX_SEC     = 6.0f;  // Startgeschwindigkeit (Pixel / Sekunde)
float    SCROLL_SPEED_MIN_PX_SEC      = 3.5f;  // Absolute Untergrenze
float    SCROLL_SPEED_MAX_PX_SEC      = 10.0f; // Absolute Obergrenze
uint32_t PROGRESSION_INTERVAL_MS      = 12000; // Alle X ms wird das Spiel schneller & Dächer kürzer
float    PROGRESSION_SPEED_FACTOR     = 1.08f; // Geschwindigkeitssteigerung (+8% pro Stufe)

// --- LÜCKEN UND DÄCHER (DAS PURE SPRING-SPIEL) ---
uint8_t  DACH_START_MIN               = 12;    // Mindestlänge Dach (in Spalten)
uint8_t  DACH_START_MAX               = 20;    // Maximallänge Dach (in Spalten)
uint8_t  DACH_ABSOLUT_MIN             = 6;     // Minimale Dachlänge bei hoher Progression

uint8_t  LUECKEN_START_MIN            = 1;     // Start Mindestlücke
uint8_t  LUECKEN_START_MAX            = 3;     // Start Maximallücke
uint8_t  LUECKEN_ABSOLUT_MIN          = 4;     // End-Mindestlücke nach Progression
uint8_t  LUECKEN_ABSOLUT_MAX          = 4;     // End-Maximallücke nach Progression
uint32_t LUECKEN_PROGRESSION_INTERVAL_MS = 10000; // Alle 10s wachsen die Lücken

// --- ZUSATZFEATURES (SETZE AUF 0, UM SIE VOLLSTÄNDIG DEAKTIVIEREN) ---
uint8_t  KISTEN_SPAWN_CHANCE_PERCENT  = 2;     // Chance (%) für Kisten auf Dächern pro Pixel (0 = AUS)
uint8_t  BRUECHIG_SPAWN_CHANCE_PERCENT= 0;     // Chance (%) für einstürzenden Boden (0 = AUS)
uint8_t  TAUBEN_SPAWN_CHANCE_PERCENT  = 0;     // Chance (%) für Tauben (0 = AUS)
uint8_t  GEFAHR_SPAWN_CHANCE_PERCENT  = 15;    // Chance (%) pro Sekunde für Trümmer (0 = AUS)

// --- TIMINGS UND FEINABSTIMMUNG ---
const uint32_t FRAME_DAUER_MS           = 25;    // 40 FPS Target
const uint32_t DUO_WINDOW_MS            = 400;   // Zeitfenster für gleichzeitiges Drücken
const uint32_t DUO_SWITCH_MS            = 8000;  // Neuer Duo-Wechsel-Intervall
const uint32_t DEBOUNCE_MS              = 30;    // Taster-Entprellzeit
const uint32_t BRUECHIG_VERZOEGERUNG_MS = 150;   // Verzögerung bis brüchiger Boden wegbricht
const uint32_t KISTEN_BREMSZEIT_MS      = 1500;  // Dauer Geschwindigkeitsverlust nach Kiste
const float    KISTEN_BREMSFAKTOR       = 0.60f; // Geschwindigkeit nach Kistenkollision (-40%)
const uint32_t GEFAHR_WARNDAUER_MS      = 600;   // Dauer Warnblinken vor Trümmereinschlag
const uint32_t GEFAHR_COOLDOWN_MS       = 5000;  // Mindestabstand zwischen Trümmern

// --- POSITIONEN (GSD KONFORM, 1 LED NACH OBEN VERSETZT) ---
const uint8_t  FIGUR_X                  = 4;     // Feste X-Position der Spielfigur
const uint8_t  BODEN_Y                  = 13;    // Y-Position der Dachoberkante (1 LED nach oben versetzt)
const uint8_t  FIGUR_STAND_Y            = 12;    // Y-Position Figur stehend (Y 12)

const uint8_t  MAX_PARTIKEL             = 24;    // Max. aktive Partikel (GSD Limit)
const uint8_t  RING_BUFFER_SIZE         = 60;    // Ringpuffergröße (GSD fordert min. 40)
const uint8_t  BG_PATTERN_SIZE          = 64;    // Parallax-Musterlänge

// GSD Farbdefinitionen
const CRGB COLOR_BACKGROUND   = CRGB(0, 0, 0);
const CRGB COLOR_PLAYER       = CRGB(240, 160, 120);
const CRGB COLOR_BODEN        = CRGB(60, 60, 60);
const CRGB COLOR_BRUECHIG     = CRGB(180, 80, 0);
const CRGB COLOR_KISTE        = CRGB(160, 80, 10);
const CRGB COLOR_MISSILE      = CRGB(255, 30, 0);
const CRGB COLOR_PIGEON       = CRGB(150, 150, 150);

const CRGB PLAYER_COLORS[NUM_PLAYERS] = {
  CRGB(255, 255, 0),   // 0: GELB  (Links)
  CRGB(0, 255, 0),     // 1: GRÜN  (Rechts)
  CRGB(255, 255, 255), // 2: WEISS (Unten)
  CRGB(0, 0, 255)      // 3: BLAU  (Hoch/Oben)
};

const uint8_t BUTTON_PINS[NUM_PLAYERS] = {
  PIN_BTN_GELB, PIN_BTN_GRUEN, PIN_BTN_WEISS, PIN_BTN_BLAU
};

// Verbindliche Sprungtrajektorie gemäß GSD v3 (30 Frames), halbierte Höhe
const int8_t JUMP_OFFSETS[30] = {
  0, -1, -2, -3, -4, -4, -4, -4, -4, -4,
 -4, -4, -4, -4, -4, -4, -4, -4, -4, -4,
 -4, -4, -3, -2, -2, -1, -1,  0,  0,  0
};

// Full 3x5 Bitmap Schrift für Ziffern 0-9 (GSD v3 Specification)
const uint16_t DIGITS_3X5[10] = {
  0x7B6F, // 0
  0x2C97, // 1
  0x73E7, // 2
  0x73CF, // 3
  0x5BC9, // 4
  0x79CF, // 5
  0x79EF, // 6
  0x7249, // 7
  0x7BEF, // 8
  0x7BCF  // 9
};

// ============================================================================
// GROSSES 5x8 PIXEL FONT SYSTEM FÜR INTRO (CANOLBALT)
// ============================================================================
struct TextChar5x8 {
  uint8_t rows[8];
  CRGB color;
};

const TextChar5x8 CANOLBALT_TEXT[] = {
  { {0x0F, 0x18, 0x18, 0x18, 0x18, 0x18, 0x18, 0x0F}, CRGB(200, 200, 200) }, // C
  { {0x00, 0x00, 0x0E, 0x01, 0x0F, 0x19, 0x19, 0x0F}, CRGB(200, 200, 200) }, // a
  { {0x00, 0x00, 0x1A, 0x19, 0x19, 0x19, 0x19, 0x19}, CRGB(200, 200, 200) }, // n
  { {0x00, 0x00, 0x0E, 0x19, 0x19, 0x19, 0x19, 0x0E}, CRGB(0, 255, 230) },   // o <-- NEON-CYAN
  { {0x18, 0x18, 0x18, 0x18, 0x18, 0x18, 0x18, 0x1F}, CRGB(255, 230, 0) },   // L <-- GELB
  { {0x18, 0x18, 0x1A, 0x19, 0x19, 0x19, 0x19, 0x1E}, CRGB(0, 255, 230) },   // b <-- NEON-CYAN
  { {0x00, 0x00, 0x0E, 0x01, 0x0F, 0x19, 0x19, 0x0F}, CRGB(200, 200, 200) }, // a
  { {0x18, 0x18, 0x18, 0x18, 0x18, 0x18, 0x18, 0x0E}, CRGB(200, 200, 200) }, // l
  { {0x08, 0x08, 0x1E, 0x08, 0x08, 0x08, 0x08, 0x06}, CRGB(200, 200, 200) }  // t
};
const uint8_t CANOLBALT_LEN = 9;

// ============================================================================
// 4. STRUKTUREN UND DATENHALTUNG
// ============================================================================
enum GameState { STATE_INTRO, STATE_START, STATE_COUNTDOWN, STATE_PLAYING, STATE_GAMEOVER };
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

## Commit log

2026-04-29 Rename OpenLuxBox_Case.stl to 3d files/OpenLuxBox_Case.stl
    [OpenLuxBox_Case.stl]
2026-04-29 Rename OpenLuxBox_Case.FCStd to 3d files/OpenLuxBox_Case.FCStd
    [OpenLuxBox_Case.FCStd]
2026-09-07 Links und Infos erneuert.
    [OpenLuxBox_Case_merged.FCStd, OpenLuxBox_Case_merged.stl, OpenLuxBox_Case_v2a.stl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]
2026-11-03 make it work on an ESP32
